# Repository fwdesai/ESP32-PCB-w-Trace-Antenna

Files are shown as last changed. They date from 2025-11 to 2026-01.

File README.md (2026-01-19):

# ESP32 PCB w Trace Antenna
ESP32 based board with integrated trace antenna
v1:

Screenshot 2025-11-26 at 11 21 25 PM



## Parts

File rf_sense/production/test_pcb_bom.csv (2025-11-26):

Designator | Footprint | Quantity | Value | LCSC Part #
C1, C2 | 0201 | 2 | 22pF | C57783
C10, C12, C13, C14, C16, C21, C22, C23, C3, C4, C6, C7, C8, C9 | 0201 | 14 | 100nF | C49062
C11, C15, C17, C18, C5 | 0402 | 5 | 10uF | C315248
C19, C20 | 0201 | 2 | 3.3pF | C85906
D1 | 0603 | 1 | LED | C2288
D2 | 0603 | 1 | LED | C12624
D3 | 0603 | 1 | LED | C2286
J1 | USB_C_Receptacle_GCT_USB4105-xx-A_16P_TopMnt_Horizontal | 1 | USB_C_Receptacle_USB2.0_16P | C3025063
L1, L2, L3 | 0201 | 3 | 2.2nH | C1329438
R1, R10, R3, R4, R6, R9 | 0201 | 6 | 5k1 | C270344
R11, R12, R5 | 0201 | 3 | 1k | C138165
R13 | 0201 | 1 | 22R | C155743
R2 | 0201 | 1 | 22R | C155743
R7, R8 | 0201 | 2 | 470R | C473464
SW1, SW3 | push_button | 2 | SW_MEC_5E | C470426
U1 | QFN-32-1EP_5x5mm_P0.5mm_EP3.7x3.7mm_ThermalVias | 1 | ESP32-C3 | C2838500
U2 | Winbond_USON-8-1EP_3x2mm_P0.5mm_EP0.2x1.6mm | 1 | W25Q16JVSS | C2843335
U3, U6 | SOT-23-6 | 2 | USBLC6-2SC6 | C7519
U4 | SOT-23-5 | 1 | SPX3819M5-L-3-3 | C9055
U5 | bmi055 | 1 | ~ | C189620
Y1 | X322540MPB4SI | 1 | Crystal_GND24 | C9010

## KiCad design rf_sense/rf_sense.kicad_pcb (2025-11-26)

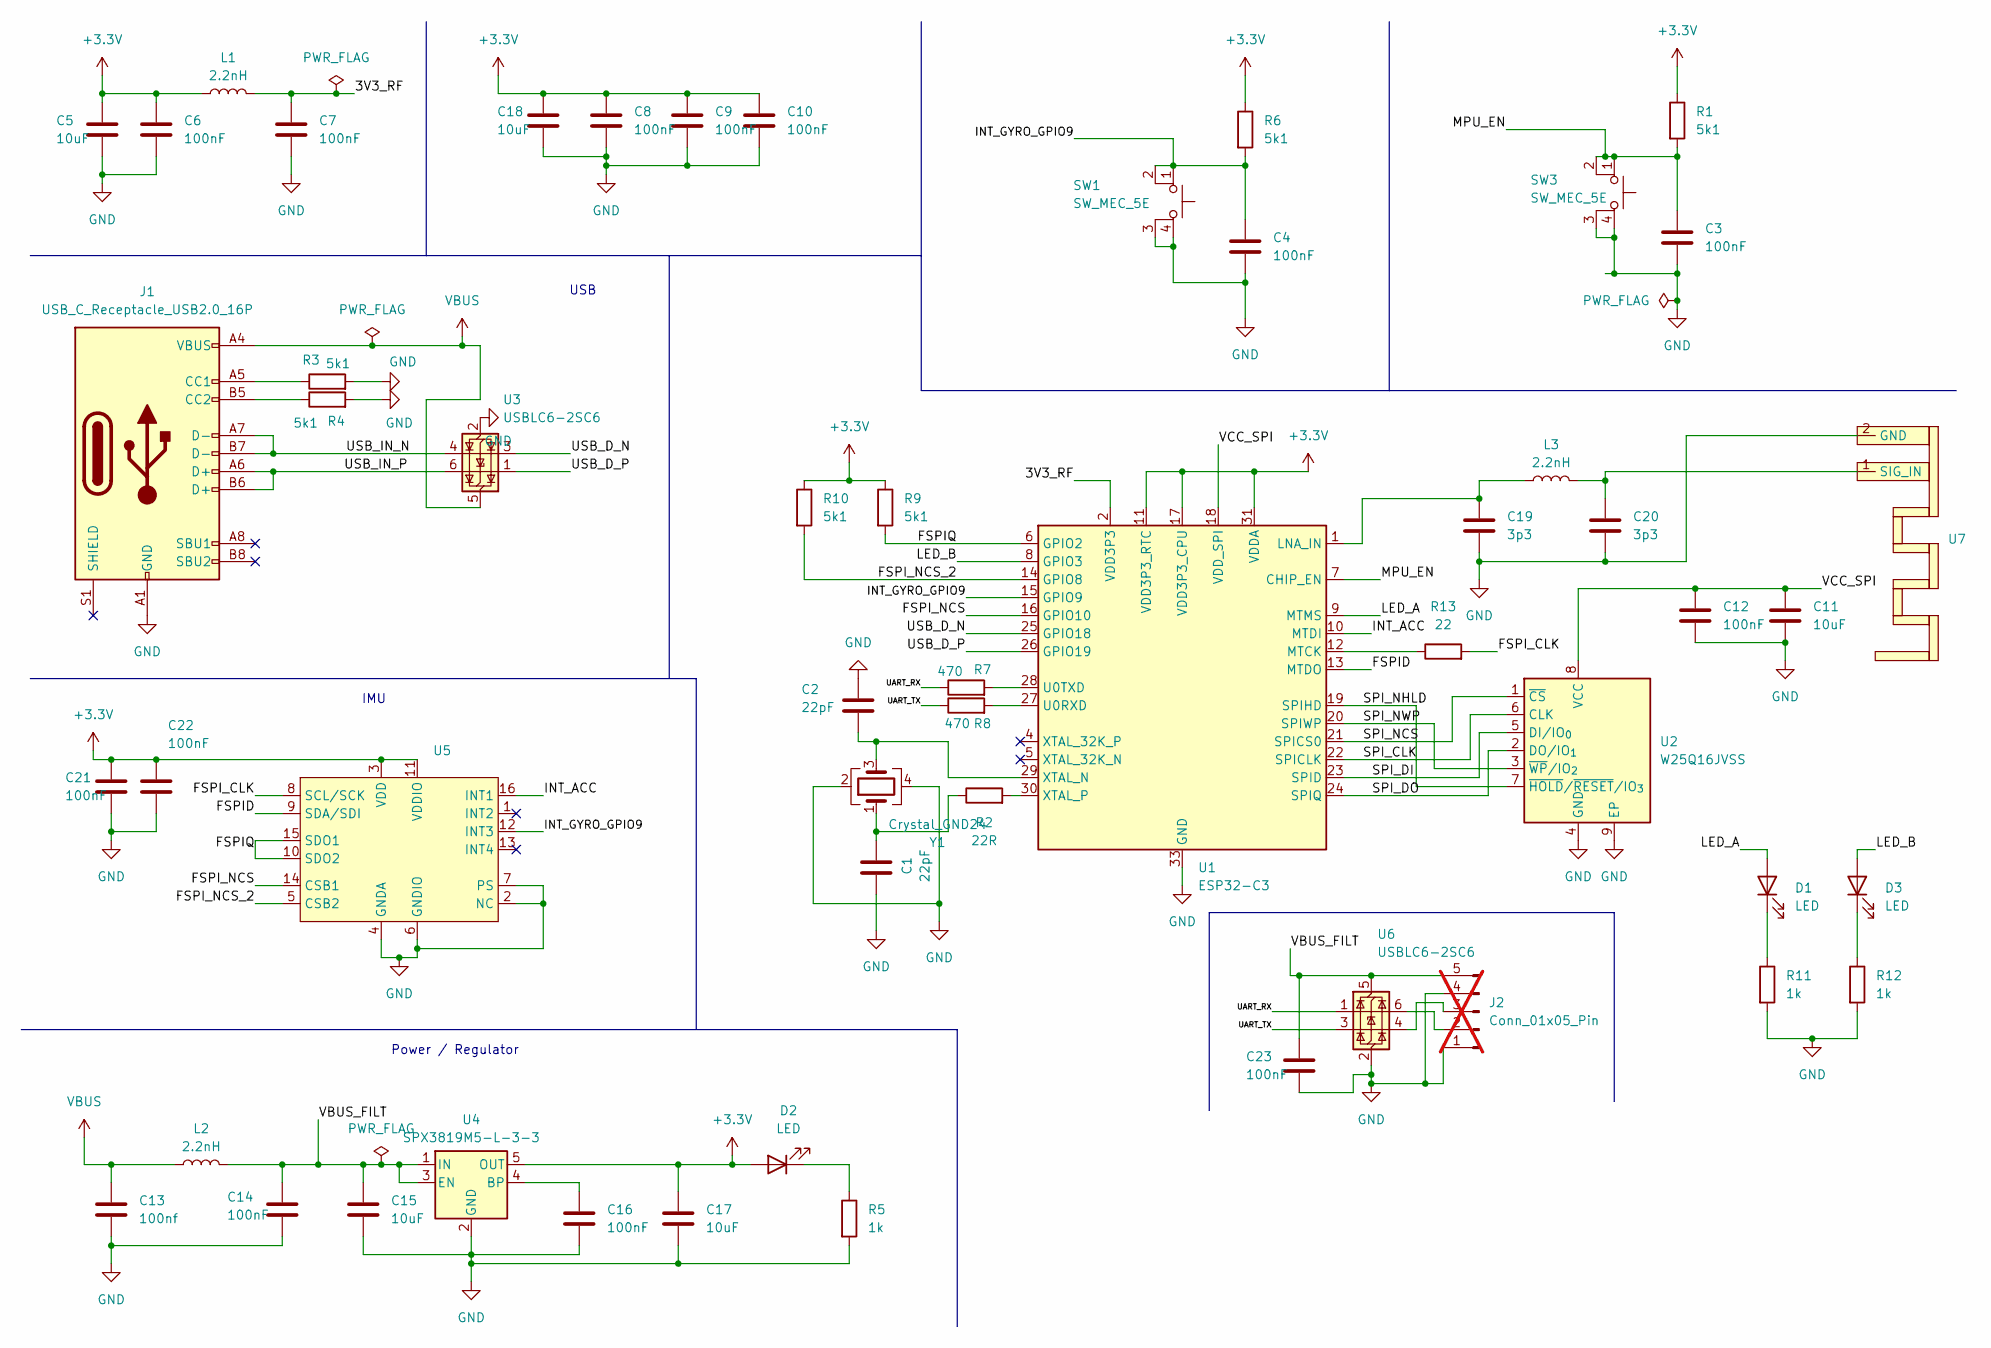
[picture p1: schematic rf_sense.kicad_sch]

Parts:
C1, C2: 22pF; C_0201_0603Metric; JLC C57783
C3, C4, C6, C7, C8, C9, C10, C12, C14, C16, C21, C22, C23: 100nF; C_0201_0603Metric; JLC C49062
C5, C11, C15, C17, C18: 10uF; C_0402_1005Metric; JLC C315248
C13: 100nf; C_0201_0603Metric; JLC C49062
C19, C20: 3p3; C_0201_0603Metric; JLC C85906
D1: LED; LED_0603_1608Metric; JLC C2288
D2: LED; LED_0603_1608Metric; JLC C12624
D3: LED; LED_0603_1608Metric; JLC C2286
J1: USB_C_Receptacle_USB2.0_16P; USB_C_Receptacle_GCT_USB4105-xx-A_16P_TopMnt_Horizontal; JLC C3025063
J2: Conn_01x05_Pin; PinHeader_1x05_P2.54mm_Vertical; not fitted
L1, L2, L3: 2.2nH; L_0201_0603Metric; JLC C1329438
R1, R3, R4, R6, R9, R10: 5k1; R_0201_0603Metric; JLC C270344
R2: 22R; R_0201_0603Metric; JLC C155743
R5, R11, R12: 1k; R_0201_0603Metric; JLC C138165
R7, R8: 470; R_0201_0603Metric; JLC C473464
R13: 22; R_0201_0603Metric; JLC C155743
SW1, SW3: SW_MEC_5E; push_button; JLC C470426
U1: ESP32-C3; QFN-32-1EP_5x5mm_P0.5mm_EP3.7x3.7mm_ThermalVias; JLC C2838500
U2: W25Q16JVSS; Winbond_USON-8-1EP_3x2mm_P0.5mm_EP0.2x1.6mm; JLC C2843335
U3, U6: USBLC6-2SC6; SOT-23-6; JLC C7519
U4: SPX3819M5-L-3-3; SOT-23-5; JLC C9055
U5: bmi055; JLC C189620
U7: test
Y1: Crystal_GND24; X322540MPB4SI; JLC C9010

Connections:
+3.3V: C5.1, C6.1, C8.1, C9.1, C10.1, C17.1, C18.1, C21.1, C22.1, D2.2 (A), L1.1, R1.1, R6.1, R9.1, R10.1, U1.11 (VDD3P3_RTC), U1.17 (VDD3P3_CPU), U1.31 (VDDA), U1.32 (VDDA), U4.5 (OUT), U5.3 (VDD), U5.11 (VDDIO)
/3V3_RF: C7.1, L1.2, U1.2 (VDD3P3), U1.3 (VDD3P3)
/FSPID: U1.13 (MTDO), U5.9 (SDA/SDI)
/FSPIQ: R9.2, U1.6 (GPIO2), U5.10 (SDO2), U5.15 (SDO1)
/FSPI_CLK: R13.2, U5.8 (SCL/SCK)
/FSPI_NCS: U1.16 (GPIO10), U5.14 (CSB1)
/FSPI_NCS_2: R10.2, U1.14 (GPIO8), U5.5 (CSB2)
/INT_ACC: U1.10 (MTDI), U5.16 (INT1)
/INT_GYRO_GPIO9: C4.1, R6.2, SW1.1, SW1.2, U1.15 (GPIO9), U5.12 (INT3)
/LED_A: D1.2 (A), U1.9 (MTMS)
/LED_B: D3.2 (A), U1.8 (GPIO3)
/MPU_EN: C3.1, R1.2, SW3.1, SW3.2, U1.7 (CHIP_EN)
/SPI_CLK: U1.22 (SPICLK), U2.6 (CLK)
/SPI_DI: U1.23 (SPID), U2.5 (DI/IO_{0})
/SPI_DO: U1.24 (SPIQ), U2.2 (DO/IO_{1})
/SPI_NCS: U1.21 (SPICS0), U2.1 (~CS)
/SPI_NHLD: U1.19 (SPIHD), U2.7 (~HOLD/~RESET/IO_{3})
/SPI_NWP: U1.20 (SPIWP), U2.3 (~WP/IO_{2})
/UART_RX: R7.1, U6.1 (I/O1)
/UART_TX: R8.1, U6.3 (I/O2)
/USB_D_N: U1.25 (GPIO18), U3.3 (I/O2)
/USB_D_P: U1.26 (GPIO19), U3.1 (I/O1)
/USB_IN_N: J1.A7 (D-), J1.B7 (D-), U3.4 (I/O2)
/USB_IN_P: J1.A6 (D+), J1.B6 (D+), U3.6 (I/O1)
/VBUS_FILT: C14.1, C15.1, C23.1, J2.5, L2.2, U4.1 (IN), U4.3 (EN), U6.5 (VBUS)
/VCC_SPI: C11.1, C12.1, U1.18 (VDD_SPI), U2.8 (VCC)
GND: C1.2, C2.2, C3.2, C4.2, C5.2, C6.2, C7.2, C8.2, C9.2, C10.2, C11.2, C12.2, C13.2, C14.2, C15.2, C16.2, C17.2, C18.2, C19.2, C20.2, C21.2, C22.2, C23.2, J1.A1 (GND), J1.A12 (GND), J1.B1 (GND), J1.B12 (GND), J2.1, J2.4, R3.2, R4.2, R5.2, R11.2, R12.2, SW1.3 (K), SW1.4 (A), SW3.3 (K), SW3.4 (A), U1.33 (GND), U2.4 (GND), U2.9 (EP), U3.2 (GND), U4.2 (GND), U5.2 (NC), U5.4 (GNDA), U5.6 (GNDIO), U5.7 (PS), U6.2 (GND), U7.2 (GND), Y1.2, Y1.4
unnamed: C1.1, R2.1, Y1.1
unnamed: D1.1 (K), R11.1
unnamed: D2.1 (K), R5.1
unnamed: D3.1 (K), R12.1
unnamed: J1.A5 (CC1), R3.1
unnamed: J1.B5 (CC2), R4.1
unnamed: J2.2, U6.6 (I/O1)
unnamed: J2.3, U6.4 (I/O2)
unnamed: C19.1, L3.1, U1.1 (LNA_IN)
unnamed: R13.1, U1.12 (MTCK)
unnamed: R8.2, U1.27 (U0RXD)
unnamed: R7.2, U1.28 (U0TXD)
unnamed: C2.1, U1.29 (XTAL_N), Y1.3
unnamed: R2.2, U1.30 (XTAL_P)
unnamed: C16.1, U4.4 (BP)
unnamed: C20.1, L3.2, U7.1 (SIG_IN)
VBUS: C13.1, J1.A4 (VBUS), J1.A9 (VBUS), J1.B4 (VBUS), J1.B9 (VBUS), L2.1, U3.5 (VBUS)

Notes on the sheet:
Power / Regulator
USB
IMU

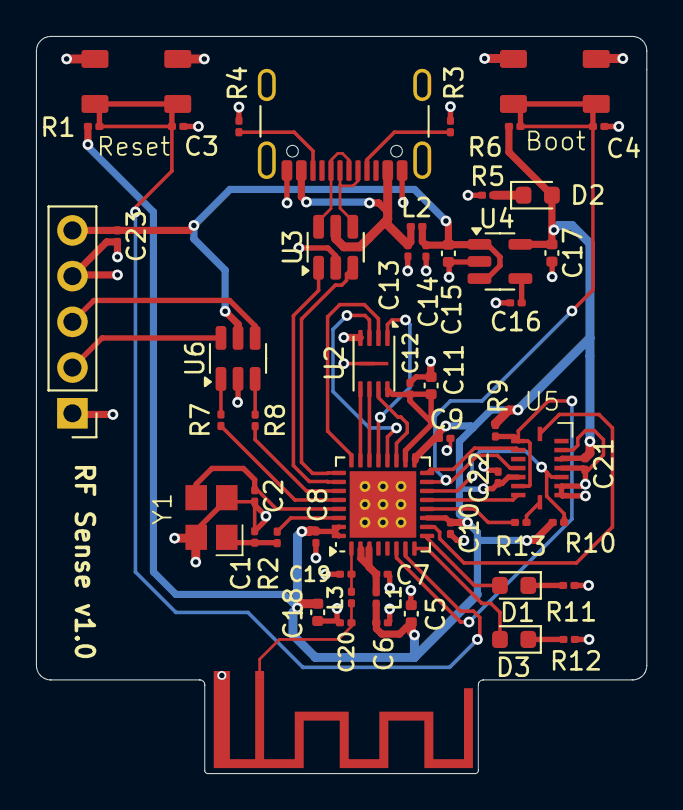
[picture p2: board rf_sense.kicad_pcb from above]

Board: 4 copper layers, 33.9 x 41.0 mm, 54 parts (0 on the bottom side), 44 nets.

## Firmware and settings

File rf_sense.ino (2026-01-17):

#include <SPI.h>
#include "soc/soc.h"

#define FSPI_CLK 6
#define FSPI_MISO 2
#define FSPI_MOSI 7
#define FSPI_ACCEL_SS 10
#define FSPI_GYRO_SS 8

#define ACCEL_INT 5
#define GYRO_INT 9

#define IMU_BUF_SIZE 128

#define COMP_FILTER_ALPHA 0.01
#define PRINT_PERIOD 200 // ms

typedef struct {
  uint64_t t_us;      // timestamp in microseconds
  //int16_t  gyro[3];  
  int16_t  accel[3];  
} ImuSample;

volatile ImuSample imu_buf[IMU_BUF_SIZE];
volatile uint16_t imu_head = 0;
volatile uint16_t imu_tail = 0;

static const int spiClk = 8000000;

SPIClass *fspi_accel = NULL;


hw_timer_t *timer = NULL;


void setup() {
  // put your setup code here, to run once:
  Serial.begin(115200);
  delay(1);
  pinMode(3, OUTPUT);

  //Set up the data interrupts
  attachInterrupt(digitalPinToInterrupt(ACCEL_INT), imu_drdy_isr, RISING);


  fspi_accel = new SPIClass(FSPI);
  fspi_accel->begin(FSPI_CLK, FSPI_MISO, FSPI_MOSI, FSPI_ACCEL_SS);

  //fspi_gyro = new SPIClass(FSPI);
  //fspi_gyro->begin(FSPI_CLK, FSPI_MISO, FSPI_MOSI, FSPI_GYRO_SS);

  pinMode(FSPI_ACCEL_SS, OUTPUT);
  pinMode(FSPI_GYRO_SS, OUTPUT);

  // turn led on
  digitalWrite(3, HIGH);

  digitalWrite(FSPI_ACCEL_SS, HIGH);
  digitalWrite(FSPI_GYRO_SS, HIGH);

  setUpIMU_accel(fspi_accel);

  // set up the hardware timer
  timer = timerBegin(1000000);    // 1 Mhz timer
  timerStart(timer);

}

void loop() {
  
  while (imu_tail != imu_head) {
    ImuSample s;
    memcpy(&s, (const void *)&imu_buf[imu_tail], sizeof(ImuSample));

    imu_tail = (imu_tail + 1) % IMU_BUF_SIZE;

    static uint64_t t_prev = 0;
      if (t_prev != 0) {
        double dt = (s.t_us - t_prev) * 1e-6;
        // use dt in filter / control loop
      }
      t_prev = s.t_us;

      process_imu(s);
  }


}

void process_imu(const ImuSample &s) {
  static uint64_t prev_print_time = 0;
  if ((timerReadMillis(timer) - prev_print_time) >= PRINT_PERIOD) {
    prev_print_time = timerReadMillis(timer);
    Serial.printf("A_x = %d, A_y = %d, A_z = %d\n", s.accel[0], s.accel[1], s.accel[2]);
  }
  
}

void setUpIMU_accel (SPIClass *spi) {
  spi->beginTransaction(SPISettings(spiClk, MSBFIRST, SPI_MODE0));
  

  // g range for accel
  digitalWrite(FSPI_ACCEL_SS, LOW);
  spi->transfer((0x00 | 0x0F));
  spi->transfer(0x03);
  digitalWrite(FSPI_ACCEL_SS, HIGH);

  // set up filtered / unfiltered data out
  digitalWrite(FSPI_ACCEL_SS, LOW);
  spi->transfer((0x00 | 0x13));   
  spi->transfer(0x00);            // 0x00 for filtered, 0x80 for unfiltered
  digitalWrite(FSPI_ACCEL_SS, HIGH);

  // filter bandwith
  digitalWrite(FSPI_ACCEL_SS, LOW);
  spi->transfer((0x00 | 0x10));
  spi->transfer(0x0B);                  // 0x0C for 125 Hz bandwidth, 0B for 62.5 Hz bandwidth
  digitalWrite(FSPI_ACCEL_SS, HIGH);

  //set up interrupt for data ready
  digitalWrite(FSPI_ACCEL_SS, LOW);
  spi->transfer((0x00 | 0x17));
  spi->transfer(0x10);
  digitalWrite(FSPI_ACCEL_SS, HIGH);

  digitalWrite(FSPI_ACCEL_SS, LOW);
  spi->transfer((0x00 | 0x1A));
  spi->transfer(0x01);
  digitalWrite(FSPI_ACCEL_SS, HIGH);

  spi->endTransaction();

}

uint8_t readReg(SPIClass *spi, uint8_t reg) {
  digitalWrite(FSPI_ACCEL_SS, LOW);
  spi->transfer(0x80 | reg);
  uint8_t v = spi->transfer(0x00);
  digitalWrite(FSPI_ACCEL_SS, HIGH);
  return v;
}

void imu_read(SPIClass *spi, int16_t *out) {

  spi->beginTransaction(SPISettings(spiClk, MSBFIRST, SPI_MODE0));

  uint8_t a_xl = readReg(spi, 0x02);
  uint8_t a_xh = readReg(spi, 0x03);
  uint8_t a_yl = readReg(spi, 0x04);
  uint8_t a_yh = readReg(spi, 0x05);
  uint8_t a_zl = readReg(spi, 0x06);
  uint8_t a_zh = readReg(spi, 0x07);

  spi->endTransaction();

  out[0] = (int16_t)((a_xh << 8) | a_xl);
  out[1] = (int16_t)((a_yh << 8) | a_yl);
  out[2] = (int16_t)((a_zh << 8) | a_zl);

}

void ARDUINO_ISR_ATTR imu_drdy_isr() {
    uint16_t next = (imu_head + 1) % IMU_BUF_SIZE;
    if (next == imu_tail) {
        Serial.println("Buffer full");
        return;
    }

    ImuSample s;
    s.t_us = timerReadMicros(timer); 

    imu_read(fspi_accel, s.accel);

    //Push to buffer
    memcpy((void *)&imu_buf[imu_head], (const void *)&s, sizeof(ImuSample));
    imu_head = next;
}
